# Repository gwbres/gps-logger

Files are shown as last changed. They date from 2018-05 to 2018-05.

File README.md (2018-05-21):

## Mini GPS data logger

The idea behind this project is to have a
long lasting GPS data logger.

The selected module is the PMTK3339 GPS receiver
provided by Adafruits on a breakout board.

An MSP430 is used to kick start the GPS module,
this device has extensive options to reduce power
consumption.

### What you can learn from this project

* How to compile code for MSP430 devices
* Use MSP430 features to reduce power consumption
* 
* Manipulate coordinates
	* D° M' S"
	* Decimal degrees
	* etc.. 
* Discover NMEA data 

### User interface

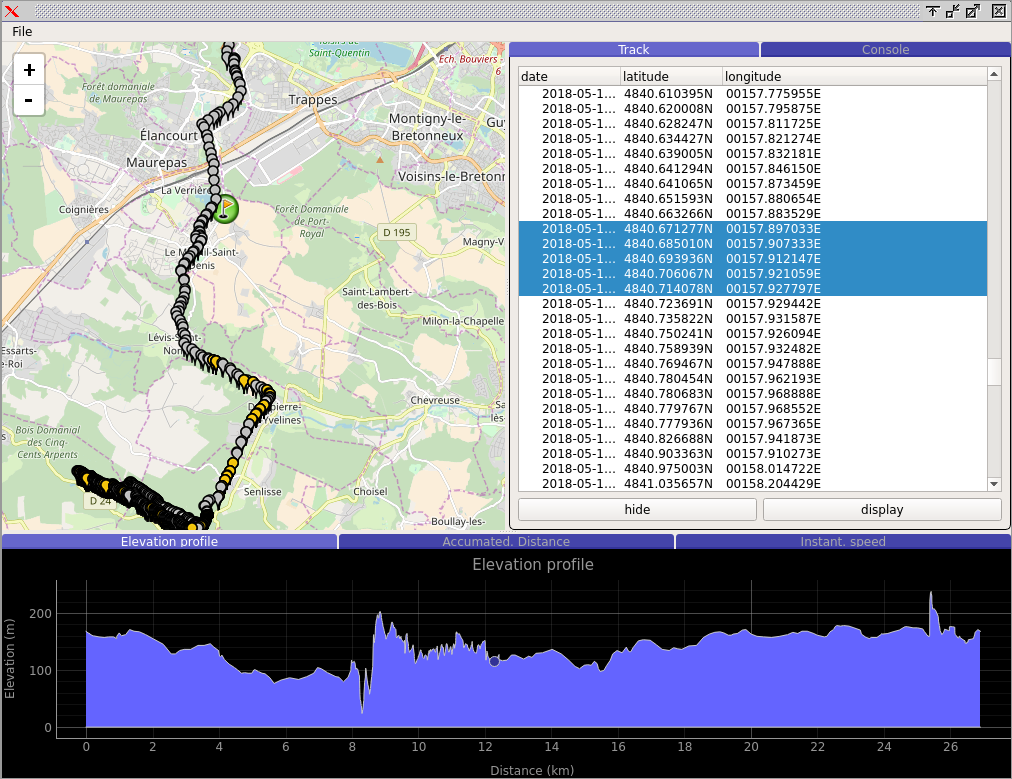
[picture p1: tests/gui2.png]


[Use the project Wiki to learn how to use the GUI & the API](https://github.com/gwbres/gps-logger/wiki)

### Getting started

Required packages:

```bash
# apt-get install binutils-msp430 gcc-msp430 msp430-libc mspdebug
```

compile the program with

```bash
make
```

I use *mspdebug* and an MSP430 launchpad to program my MCUs:

```bash
# mspdebug rf2500
# erase
# prog main.hex
# run
```

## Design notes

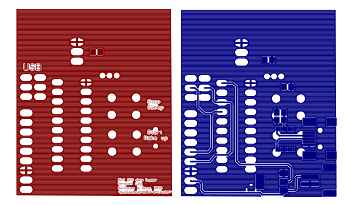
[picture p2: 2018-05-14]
PCB/top-bottom.png

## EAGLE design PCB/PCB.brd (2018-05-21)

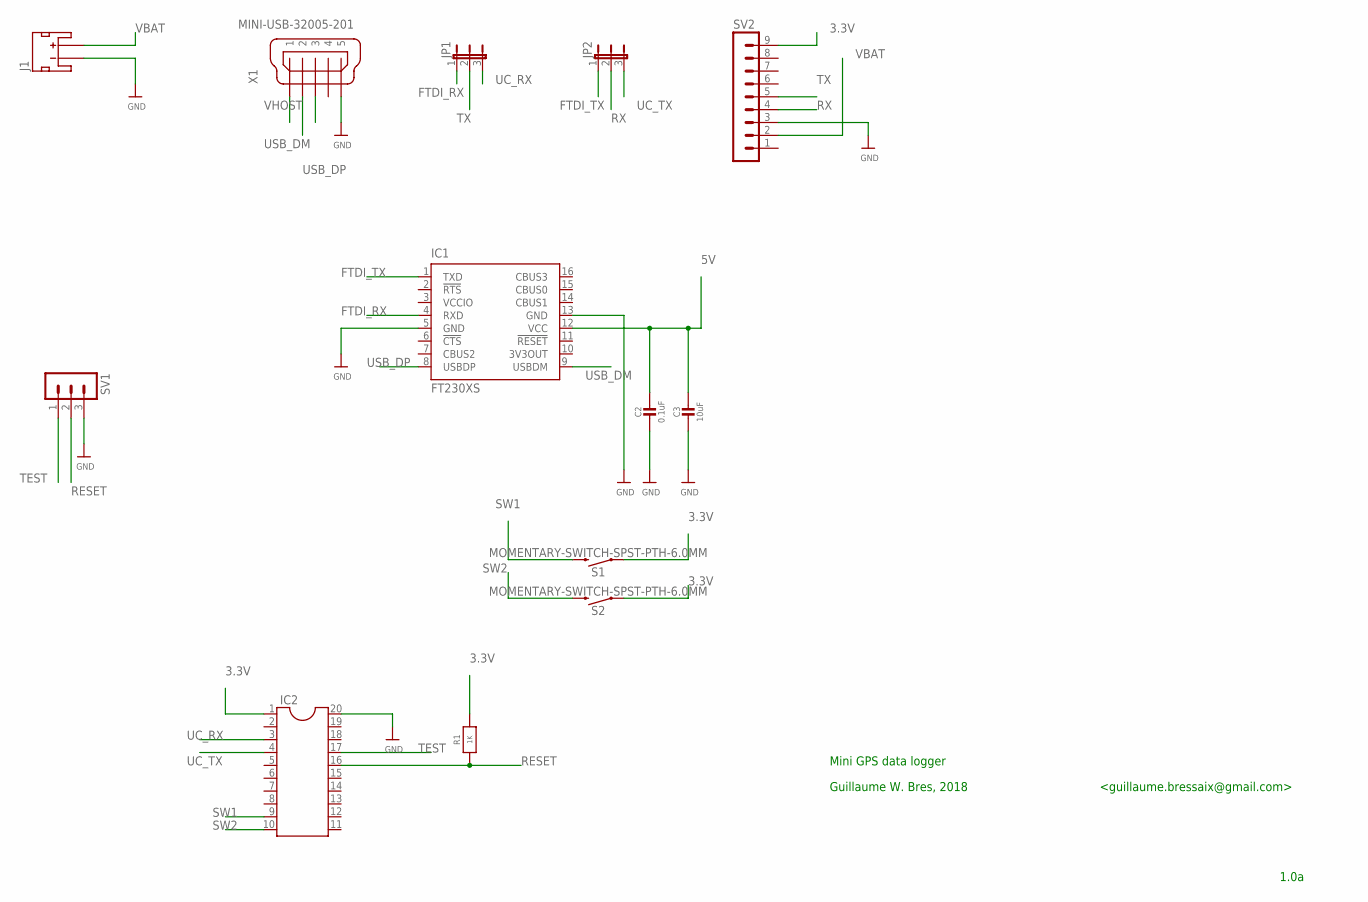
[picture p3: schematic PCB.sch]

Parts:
C2: 0.1uF; 0805-NO
C3: 10uF; 0805-NO
IC1: FT230XS; SSOP16
IC2: DIL20
J1: JST_2MM_MALE; JST-2-SMD
JP1, JP2: JP2E; JP2
R1: 1K; 0805-NO
S1, S2: MOMENTARY-SWITCH-SPST-PTH-6.0MM; TACTILE_SWITCH_PTH_6.0MM
SV1: MA03-1
SV2: MA09-1
X1: MINI-USB-32005-201; 32005-201

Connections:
3.3V: IC2.1, R1.2, S1.1, S2.1, SV2.9
5V: C2.1, C3.1, IC1.12 (VCC)
FTDI_RX: IC1.4 (RXD), JP1.1
FTDI_TX: IC1.1 (TXD), JP2.1
GND: C2.2, C3.2, IC1.5 (GND), IC1.13 (GND), IC2.20, J1.1 (-), SV1.3, SV2.3, X1.5
RESET: IC2.16, R1.1, SV1.2
RX: JP2.2, SV2.4
SW1: IC2.9, S1.3 (2)
SW2: IC2.10, S2.3 (2)
TEST: IC2.17, SV1.1
TX: JP1.2, SV2.5
UC_RX: IC2.3, JP1.3
UC_TX: IC2.4, JP2.3
USB_DM: IC1.9 (USBDM), X1.2
USB_DP: IC1.8 (USBDP), X1.3
VBAT: J1.2 (+), SV2.2
VCCIO: IC1.3 (VCCIO)
VHOST: X1.1

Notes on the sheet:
Guillaume W. Bres, 2018
Mini GPS data logger
1.0a
<guillaume.bressaix@gmail.com>

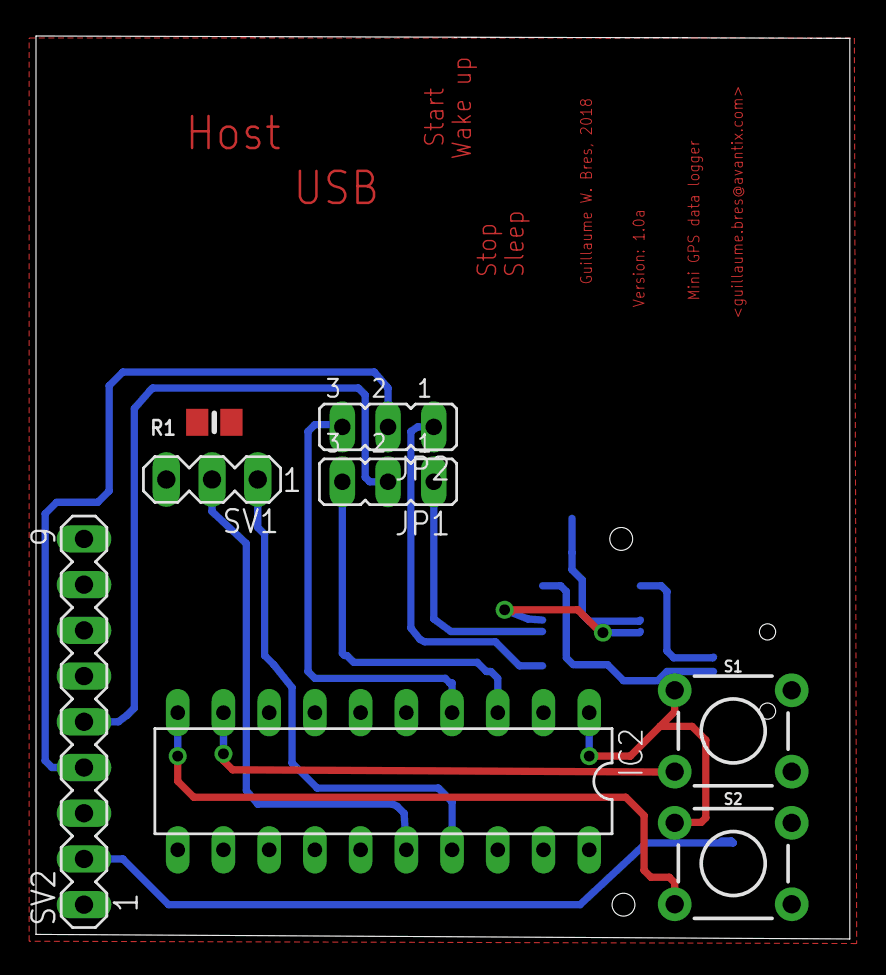
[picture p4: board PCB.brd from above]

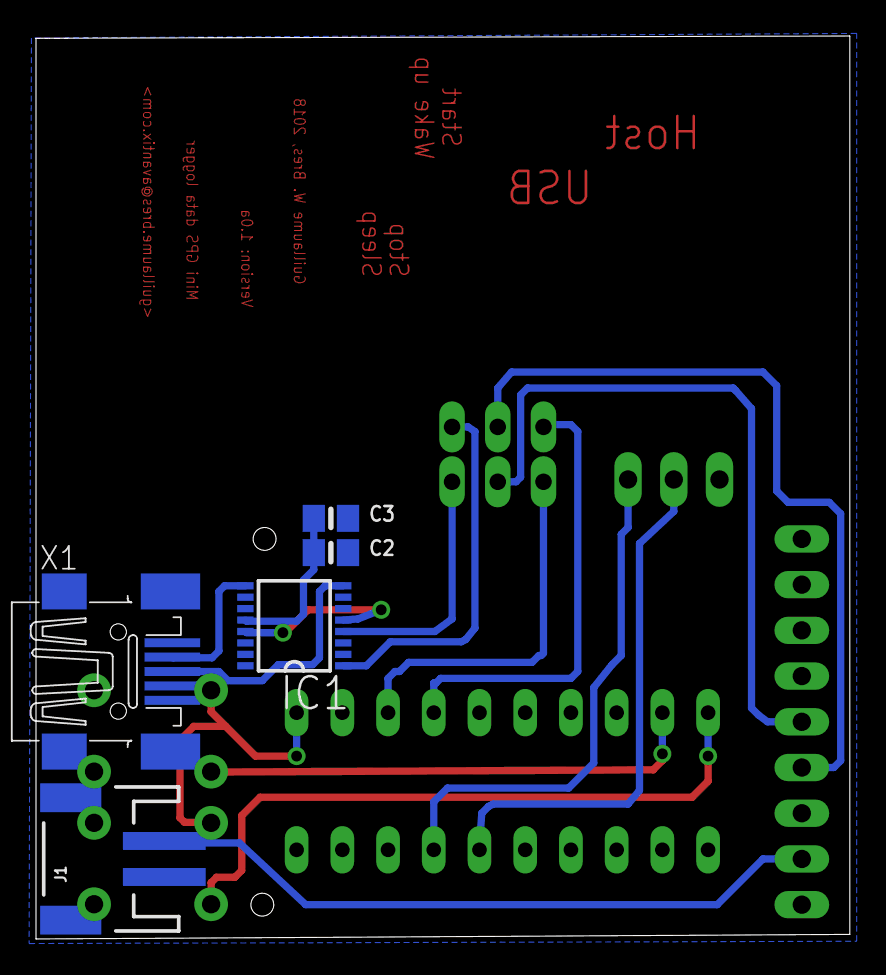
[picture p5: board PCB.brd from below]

Board: 2 copper layers, 45.2 x 50.2 mm, 13 parts (5 on the bottom side), 16 nets.

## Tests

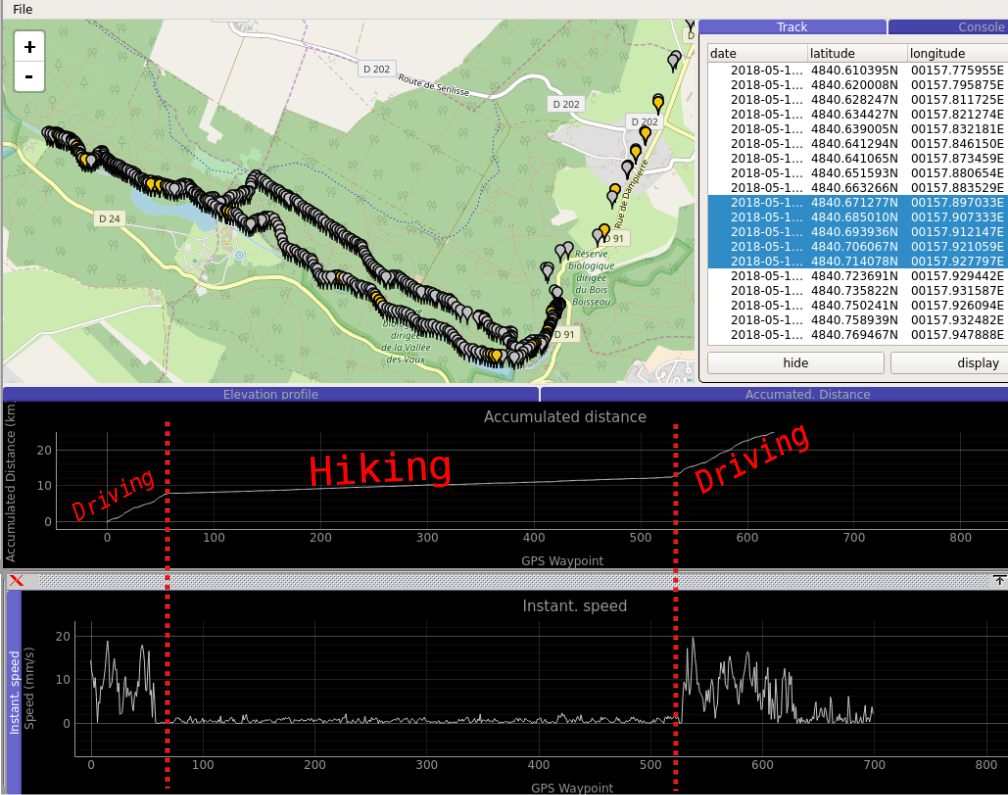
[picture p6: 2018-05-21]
tests/gui3.png

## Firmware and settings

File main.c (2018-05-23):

/*
	Guillaume W. Bres, 2018  <guillaume.bres@noisext.com>

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
	THE SOFTWARE IS PROVIDED "AS IS", WITHOUT WARRANTY OF ANY KIND, EXPRESS OR
	IMPLIED, INCLUDING BUT NOT LIMITED TO THE WARRANTIES OF MERCHANTABILITY,
	FITNESS FOR A PARTICULAR PURPOSE AND NONINFRINGEMENT. IN NO EVENT SHALL THE
	AUTHORS OR COPYRIGHT HOLDERS BE LIABLE FOR ANY CLAIM, DAMAGES OR OTHER
	LIABILITY, WHETHER IN AN ACTION OF CONTRACT, TORT OR OTHERWISE, ARISING FROM,
	OUT OF OR IN CONNECTION WITH THE SOFTWARE OR THE USE OR OTHER DEALINGS IN
	THE SOFTWARE.
*/

#include "GPS.h"
#include <string.h>
#include <msp430g2553.h>

// P1
#define RXD 			BIT1
#define TXD 			BIT2
// P2
#define START_BTN		BIT2
#define STOP_BTN		BIT1
#define ERASE_BTN		BIT0
#define LED 			BIT3

#define BUFSIZE	128
volatile int tx_ptr;
volatile int bytes_to_send;
char tx_buf[BUFSIZE];

volatile char rx_done;

volatile uint8_t _user_action;
volatile uint8_t debouncing;
volatile int debounce_cnt;
#define DEBOUNCE_CNT_MAX	1024

#ifdef LOW_POWER
	volatile int wdcnt;
	#define WDT_NO_ACT	256
#endif

void init_gpio(void);
void init_uart(void);
void init_timers(void);
void init_platform(void);
void wait_for_answer(void);

int main(int argc, char **argv){
	init_platform();

	while(1){
		if (_user_action & 0x01){
			// P2OUT |= GPS_EN;
			GPS_start_logging();
			wait_for_answer();
			_user_action &= 0x00;
			while(debouncing);
			_BIS_SR(GIE|P1IE|LPM3_bits); // hibernate
		} 
		/*else if (_user_action & 0x02){
			GPS_stop_logging();
			wait_for_answer();
			// P2OUT &= ~GPS_EN;
			_user_action &= 0x00;

		} else if (_user_action & 0x04){
			GPS_erase_flash();
			wait_for_answer();
			_user_action &= 0x00;
		}*/
	}
	return 0;
}

void init_platform(void){
	if (CALBC1_1MHZ == 0xff || CALDCO_1MHZ == 0xff){while(1);}
	BCSCTL1 = CALBC1_1MHZ;
	DCOCTL = CALDCO_1MHZ;
	WDTCTL = WDTPW + WDTHOLD;

	init_gpio();
	init_timers();
	init_uart();

	_BIS_SR(GIE|P1IE);
	GPS_NMEA_output(PMTK_NMEA_OFF); // reduces power drawn by module
	_BIS_SR(GIE|P1IE|LPM3_bits); // hibernate
}

void init_timers(void){
	TACTL |= MC_0; // stop
	TACTL = TASSEL_2 + ID_2 + TAIE; // SMCLK
	TA0R = 0;
	// debouncer will run for
	// (CCR0+1)*DEBOUNCE_CNT_MAX/1E6 [s]
	CCR0 = 128-1;
	CCTL0 |= CCIE; // CCR0 IE
	TACTL |= MC_2; // continuous op. mode
}

void init_gpio(void){
	P1DIR |= RXD+TXD;
	P1SEL |= RXD+TXD; // USCI requires 
	P1SEL2 |= RXD+TXD; // special opmode
	P1OUT &= 0x00;

	//P2DIR |= GPS_EN;
	// P2OUT |= GPS_EN;
	P2DIR |= LED;
	P2OUT &= 0x00;
	P2IE |= START_BTN+STOP_BTN+ERASE_BTN; // enable required ISR
	// clear related flags
	P2IFG &= ~START_BTN; 
	P2IFG &= ~STOP_BTN;
	P2IFG &= ~ERASE_BTN;
	// initialize
	_user_action &= 0x00;
	debounce_cnt = 0;
	debouncing &= 0x00;
}

void init_uart(void){
	UCA0CTL1 |= UCSSEL_2; // SMCLK
	UCA0BR0 = 109; // 9600 b/s @1M
	UCA0BR1 = 0x00; // 9600 b/s @1M
	UCA0MCTL = UCBRS2 + UCBRS0; // 5% modulation
	UCA0CTL1 &= ~UCSWRST;
	// disable ISR 
	UC0IE &= ~UCA0TXIE;
	UC0IE &= ~UCA0RXIE;
	rx_done &= 0x00;
}

void wait_for_answer(void){
/* TODO should wait proper answer 
	rx_done &= 0x00;
	UC0IE |= UCA0RXIE;
	while (!rx_done);
*/
	__delay_cycles(0xffff);
}

#pragma vector = TIMER0_A0_VECTOR
__interrupt void CCR0_ISR(void){
	if (debouncing){
		if (debounce_cnt < DEBOUNCE_CNT_MAX-1){
			debounce_cnt++;
			P2OUT ^= LED;
		} else {
			debounce_cnt &= 0;
			debouncing &= 0x00;
		}
	}
	TA0R = 0;
}

#pragma vector = PORT2_VECTOR
__interrupt void P2_ISR(void){
	if (!debouncing){ 
		debounce_cnt &= 0;
		debouncing |= 0x01;
		P2OUT ^= LED;
		__bic_SR_register_on_exit(LPM3_bits);

		if (P2IFG & START_BTN)
			_user_action |= 0x01;
		else if (P2IFG & STOP_BTN)
			_user_action |= (0x01<<1);
		else if (P2IFG & ERASE_BTN)
			_user_action |= (0x01<<2);
	}
	
	// clear flag
	if (P2IFG & START_BTN) P2IFG &= ~START_BTN;
	if (P2IFG & STOP_BTN) P2IFG &= ~STOP_BTN;
	if (P2IFG & ERASE_BTN) P2IFG &= ~ERASE_BTN;
}

#pragma vector = USCIAB0TX_VECTOR
__interrupt void USCI0TX_ISR(void){
	UCA0TXBUF = tx_buf[tx_ptr++];
	if (tx_ptr == bytes_to_send-1){ // tx done
		UC0IE &= ~UCA0TXIE; // disable TX ISR
	} 
}

#pragma vector = USCIAB0RX_VECTOR
__interrupt void USCI0RX_ISR(void){
	if (UCA0RXBUF == '\n'){ // PMTK module answered
		rx_done |= 0x01;
		UC0IE &= ~UCA0RXIE; // we're done
	} 
}

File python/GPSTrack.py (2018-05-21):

from Waypoint import *

class GPSTrack:
	"""
	GPS track is a list of GPS waypoints
	"""
	
	def __init__(self, fp):
		"""
		Builds GPS Track by parsing all waypoints
		in either NMEA or KML file
		"""
		self.waypoints = []

		ext = fp.split('.')[-1]
		if (ext == 'nmea'):
			self.GPSTrackNMEA(fp)
		
		elif (ext == 'kml'):
			self.GPSTrackKML(fp)
		
		elif (ext == 'locus'):
			self.GPSTrackLOCUS(fp)
		
		else:
			raise ValueError("GPS Track cannot be built from a '.{:s}' log file".format(ext))

	def GPSTrackNMEA(self, fp):
		"""
		Builds GPS Track by parsing all waypoints
		in .nmea log file
		"""
		fd = open(fp,"r")
		for line in fd:
			line = line.strip()
			try:
				self.waypoints.append(Waypoint(nmea=line))
			except NameError: # not $GGA or $RMC frame
				pass

		fd.close()

	def GPSTrackKML(self, fp):
		"""
		Builds GPS Track by parsing all waypoints
		in .kml log file
		"""
		fd = open(fp,"r")
		coordinates_found = False
		for line in fd:
			line = line.strip()
		
			if (not(coordinates_found)):
				if ("<coordinates>" in line):
					coordinates_found = True
		
			else:
				if ("</coordinates>" in line):
					break
				else:
					parsed = line.split(",")
					lat = float(parsed[1])
					lon = float(parsed[0])
					alt = parsed[2]
					self.waypoints.append(Waypoint(latDeg=lat,lonDeg=lon,alt=alt))

		fd.close()

	def GPSTrackLOCUS(self, fp):
		"""
		Builds GPS Track by parsing all waypoints
		in .locus log file
		"""
		fd = open(fp,"r")
		for line in fd:
			line = line.strip()

			if (not(line.startswith("$PMTKLOX,1"))):
				# non valid locus log
				continue

			# locus payload parsing
			content = line.split(",")
			checksum = content[-1].split("*")[-1]
			expected = Waypoint.checksum(line)
			if (checksum != expected):
				# checksum is faulty, discard this line
				continue
			
			content = content[3:] # remove header, type & line number
			content[-1] = content[-1].split("*")[0] # remove checksum value
			
			# one line in locus contains 6 waypoints
			# build byte array for this line
			_bytes = []
			for c in content:
				for i in range(0, 4): # 4*2 characters
					_offset = int(i*2) # slice 2 by 2 characthers (hex format)
					_bytes.append(int(c[_offset:_offset+2],16))

			N = int(len(content)/4) # number of records for this line
			for i in range(0,N): 
				try: 
					self.waypoints.append(Waypoint(locus=_bytes))
				except ValueError:
					# missing GPS fix, discard this one 
					pass

				_bytes = _bytes[16:] # shift used bytes

		fd.close()

	def __len__(self):
		""" GPS Track lenght returns number of waypoints """
		return len(self.waypoints)

	def __iter__(self):
		""" Iterator over GPS track """
		return iter(self.waypoints)

	def __reversed__(self):
		""" Iterates backwards over GPS track """
		return reversed(self.waypoints)

	def __setitem__(self, index, wp):
		""" Sets waypoint at given index in track """
		self.waypoints[index] = wp

	def __getitem__(self, index):
		""" Returns waypoint in GPS track at given index """
		return self.waypoints[index]
	
	def __delitem__(self, index):
		""" Removes given waypoint in track """
		del self.waypoints[index]

	def __str__(self):
		string = "--- GPS Track ---\n"
		for i in range(0, len(self.waypoints)):
			string += str(self.waypoints[i])
		string += "----------------"
		return string

	def getWaypoints(self):
		"""
		Returns all waypoints contained in track
		"""
		return self.waypoints

	def append(self, waypoints):
		"""
		Appends waypoint or list of waypoints
		to self
		"""
		self.waypoints.append(waypoints)
	
	def prepend(self, waypoints):
		"""
		Prepends waypoint or list of waypoints
		to self
		"""
		self.waypoints.insert(0, waypoints)

	def insert(self, index, waypoints):
		"""
		Inserts waypoint or list of waypoints
		at given position
		"""
		self.waypoints.insert(index, waypoints)

	def toKML(self, fp):
		"""
		Writes GPS track in a KML file
		"""
		fd = open(fp, "w")

		# initialize kml file
		fd.write('<?xml version="1.0" encoding="UTF-8"?>\n')
		fd.write('<kml xmlns="http://earth.google.com/kml/2.2" xmlns:gx="http://www.google.com/kml/ext/2.2">\n')
		fd.write('<Folder>\n')

		# track infos
		fd.write('\t<name>Imported from {:s}</name>\n'.format(fp))
		fd.write('\t<Placemark>\n')
		fd.write('\t\t<name>Track</name>\n')

		# track style
		fd.write('\t\t<Style>\n')
		fd.write('\t\t\t<LineStyle>\n')
		fd.write('\t\t\t\t<color>00cc00cc</color>\n')
		fd.write('\t\t\t\t<width>4</width>\n')
		fd.write('\t\t\t</LineStyle>\n')
		fd.write('\t\t</Style>\n')

		# track
		fd.write('\t\t<LineString>\n')
		fd.write('\t\t\t<altitudeMode>relativeToGround</altitudeMode>\n')
		fd.write('\t\t\t<coordinates>\n')

		for i in range(0, len(self.waypoints)):
			[lat, lon] = self.waypoints[i].toDecimalDegrees()
			fd.write('\t\t\t\t{:f},{:f},{:s}\n'.format(lon,lat,self.waypoints[i].getAltitude()))

		fd.write('\t\t\t</coordinates>\n')
		fd.write('\t\t</LineString>\n')
		
		# finalize kml file 
		fd.write('\t</Placemark>\n')
		fd.write('\t</Folder>\n')
		fd.write('</kml>\n')
		fd.close()
		print("GPS track written into {:s}".format(fp))

	def toGPX(self, fp):
		"""
		Writes GPS track in a GPX file
		"""
		fd = open(fp,"w")
		fd.write('<?xml version="1.0" encoding="UTF-8"?>\n')
		fd.write('<gpx version="1.0" xmlns:xsi="http://www.w3.org/2001/XMLSchema-instance"\n')
		fd.write(' xmlns="http://www.topografix.com/GPX/1/0"\n')
		fd.write(' xsi:schemaLocation="http://www.topografix.com/GPX/1/0 http://www.topografix.com/GPX/1/0/gpx.xsd">\n')

		fd.write('\t<name>{:s}</name>\n'.format(fp))
		fd.write('\t<desc>Imported from {:s}</desc>\n'.format(fp))
		fd.write('\t<trk>\n')
		fd.write('\t\t<name>GPS Track</name>\n')
		fd.write('\t\t<number>1</number>\n')
		fd.write('\t\t<trkseg>\n')
	
		for i in range(0, len(self.waypoints)):
			[lat, lon] = self.waypoints[i].toDecimalDegrees()
			fd.write('\t\t\t<trkpt lat="{:f}" lon="{:f}">\n'.format(lat,lon))
			fd.write('\t\t\t\t<ele>{:s}</ele>\n'.format(self.waypoints[i].getAltitude()))
			fd.write('\t\t\t</trkpt>\n')
			
		fd.write('\t\t</trkseg>\n')
		fd.write('\t</trk>\n')
		fd.write('</gpx>')
		fd.close()
		print("GPS Track written into {:s}".format(fp))

	def toCSV(self, fp):
		"""
		Writes GPS Track in CSV format,
		line0: titles[0], titles[1], .., titles[n-1]
		line[1]: data[0][0], ..., data[0][n-1]
		line[l-1]: data[l-1][0], ..., data[l-1][n-1]
		"""
		fd = open(fp,"w")
		line = ""
		fd.write("lat,lon,alt\n") # add 'label' here to view extra info
	
		for i in range(0, len(self.waypoints)):
			[lat, lon] = self.waypoints[i].toDecimalDegrees()
			line = "{:f},{:f},{:s}\n".format(lat,lon,self.waypoints[i].getAltitude())
			fd.write(line)
		fd.close()
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

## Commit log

2018-04-15 added UART initialization + hello world
2018-04-21 introduced lowpower mode; finalized UART demo; working on PIE: GPIO interrupt
2018-04-21 do not track .nmea & .kml data files
2018-04-22 do not track .gpx files
2018-04-23 fixed NMEA->KML and NMEA->GPX conversions
    [tools.py]
2018-04-25 fixed degree to D,M,S converion, fixed nmea->kml & nmea->gpx conversion, introduced geoplotlib to visualize waypoints
    [tools.py]
2018-04-25 fixed serial.open problem: class constructor already does the job
    [tools.py]
2018-05-02 introduced status logic & added status LED
2018-05-12 corrected x axis
2018-05-13 added PCB 1.0
    [PCB.sch]
2018-05-13 added board 1.0: still WIP
    [PCB.brd]
2018-05-13 hide eagle/board routing related files
2018-05-13 added GPS Track object
2018-05-13 added PCB section
2018-05-14 use checksum to check line content, faulty coordinates will now raise an error
    [GPSTrack.py, Waypoint.py]
2018-05-14 verify checksum: raise error when faulty
    [Waypoint.py]
2018-05-14 catch error: do not append waypoint to GPS Track when checksum is faulty. This naturally discards faulty caracters in log files
    [GPSTrack.py]
2018-05-14 added PCB 1.0 (still WIP)
2018-05-14 added PCB picture
2018-05-14 modified PCB1.0
2018-05-15 added TotalDistance method, used in drawOnMap method for x axis
2018-05-16 added Track constructore from locus log: parsing is made here because locus/log may contain N records; only appends valid coordinates
2018-05-17 do not track locus log files
2018-05-17 removed deprecated geoplot lib. replaced by qMap
    [GPSTrack.py]
2018-05-18 removed deprecated script: replaced by console/command line interface
    [tools.py]
2018-05-18 corrected status & sendCommand()
    [PMTK.py]
2018-05-18 removed track viewer
2018-05-18 append all gps tracks in case several were selected
2018-05-19 added proto board 1.0
2018-05-19 introduced QListWidget to control Track visualization
2018-05-19 introduced navigation through GPS track
2018-05-21 corrected distance calculation: requires coordinates in decimal degrees
    [Waypoint.py]
2018-05-21 v1.0 almost done
    [PCB.brd, PCB.sch]

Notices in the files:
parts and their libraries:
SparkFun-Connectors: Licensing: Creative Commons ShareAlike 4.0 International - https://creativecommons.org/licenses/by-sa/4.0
